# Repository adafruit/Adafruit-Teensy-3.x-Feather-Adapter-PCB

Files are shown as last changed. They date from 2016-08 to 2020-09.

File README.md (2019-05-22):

## Adafruit Teensy 3.x Feather Adapter PCB
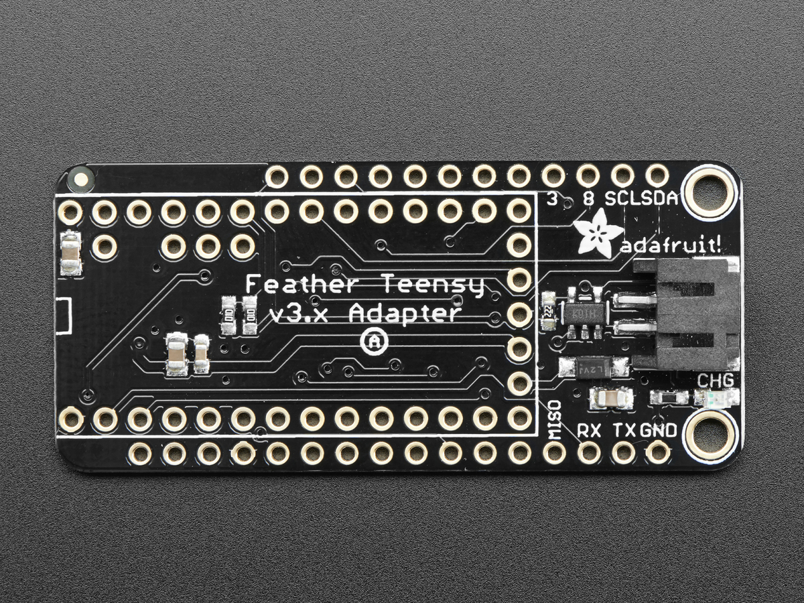
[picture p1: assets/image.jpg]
<a href="http://www.adafruit.com/products/3200"><br/>
Click here to purchase one from the Adafruit shop</a>

This Feather adapter rearranges the pins of a Teensy 3.x to give you the same shape and pinout for our Feathers. We've tested our FeatherWings so far and all are drop-in compatible. It's a great way to take advantage of the Feather ecosystem. Give your Teensy a stepper/DC motor driver, GPS, LED matrix or OLED add-on with ease. With the space left over, we even added in a 500mA LiPoly charger that automatically charges over USB and will switch over to the LiPo when USB is unplugged. There's also a 100K resistor divider for monitoring the battery voltage connected to A7

PCB files for the Adafruit Teensy 3.x Feather Adapter. The format is EagleCAD schematic and board layout
- https://www.adafruit.com/product/3200

### License

Adafruit invests time and resources providing this open source design, please support Adafruit and open-source hardware by purchasing products from [Adafruit](https://www.adafruit.com)!

All text above must be included in any redistribution

Designed by Limor Fried/Ladyada for Adafruit Industries.
Creative Commons Attribution/Share-Alike, all text above must be included in any redistribution. 
See license.txt for additional information.

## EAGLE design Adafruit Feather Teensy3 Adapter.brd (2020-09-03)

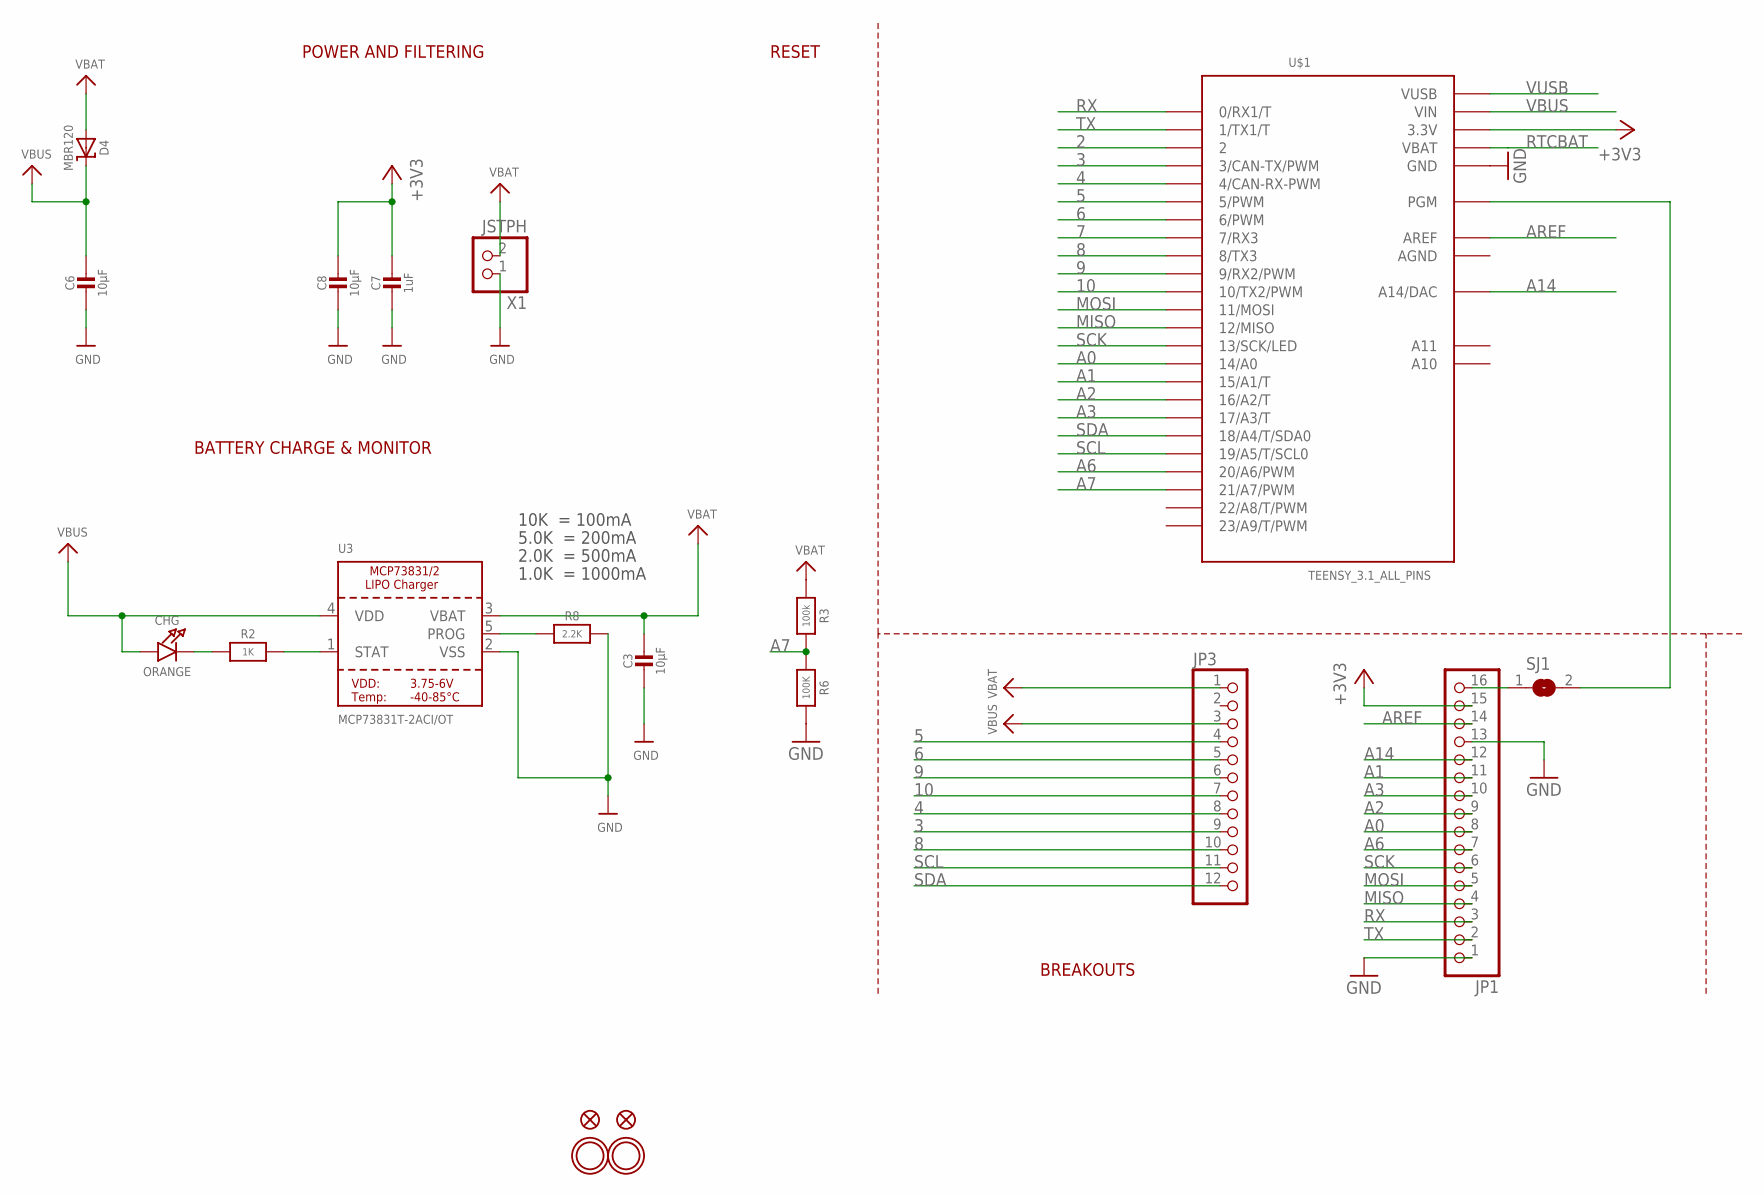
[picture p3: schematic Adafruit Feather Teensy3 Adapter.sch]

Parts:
C3, C6, C8: 10µF; 0805-NO
C7: 1uF; 0603-NO
CHG: ORANGE; CHIPLED_0805_NOOUTLINE
D4: MBR120; SOD-123
JP1: HEADER-1X16ROUND; 1X16_ROUND
JP3: HEADER-1X12; 1X12_ROUND
R2: 1K; 0603-NO
R3: 100k; 0603-NO
R6: 100K; 0603-NO
R8: 2.2K; 0603-NO
SJ1: SOLDERJUMPERCLOSED; SOLDERJUMPER_CLOSEDWIRE
U3: MCP73831T-2ACI/OT; SOT23-5
U$1: TEENSY_3.1_ALL_PINS; TEENSY3-ALL_PINS
U$31, U$32: MOUNTINGHOLE2.5; MOUNTINGHOLE_2.5_PLATED
U$34, U$35: FIDUCIAL""; FIDUCIAL_1MM
X1: JSTPH; JSTPH2

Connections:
2: U$1.2
3: JP3.9, U$1.3 (3/CAN-TX/PWM)
4: JP3.8, U$1.4 (4/CAN-RX-PWM)
5: JP3.4, U$1.5 (5/PWM)
6: JP3.5, U$1.6 (6/PWM)
7: U$1.7 (7/RX3)
8: JP3.10, U$1.8 (8/TX3)
9: JP3.6, U$1.9 (9/RX2/PWM)
10: JP3.7, U$1.10 (10/TX2/PWM)
+3V3: C7.1, C8.1, JP1.15, U$1.3.3V, U$1.3.3V1 (3.3V)
A0: JP1.8, U$1.14/A0
A1: JP1.11, U$1.15/A1 (15/A1/T)
A2: JP1.9, U$1.16/A2 (16/A2/T)
A3: JP1.10, U$1.17/A3 (17/A3/T)
A6: JP1.7, U$1.20/A6 (20/A6/PWM)
A7: R3.2, R6.1, U$1.21/A7 (21/A7/PWM)
A14: JP1.12, U$1.RESET/DAC (A14/DAC)
AGND: U$1.AGND
AREF: JP1.14, U$1.AREF
BOOT: SJ1.2, U$1.PGM
GND: C3.2, C6.2, C7.2, C8.2, JP1.1, JP1.13, R6.2, R8.2, U3.2 (VSS), U$1.GND, U$1.GND1 (GND), X1.1
MISO: JP1.4, U$1.12 (12/MISO)
MOSI: JP1.5, U$1.11 (11/MOSI)
unnamed: CHG.C, R2.1
unnamed: R2.2, U3.1 (STAT)
unnamed: R8.1, U3.5 (PROG)
RST/BOOT: JP1.16, SJ1.1
RTCBAT: U$1.VBAT
RX: JP1.3, U$1.0 (0/RX1/T)
SCK: JP1.6, U$1.13 (13/SCK/LED)
SCL: JP3.11, U$1.19/A5 (19/A5/T/SCL0)
SDA: JP3.12, U$1.18/A4 (18/A4/T/SDA0)
TX: JP1.2, U$1.1 (1/TX1/T)
VBAT: C3.1, D4.A, JP3.1, R3.1, U3.3 (VBAT), X1.2
VBUS: C6.1, CHG.A, D4.C, JP3.3, U3.4 (VDD), U$1.VIN
VUSB: U$1.VUSB

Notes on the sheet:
POWER AND FILTERING
RESET
10K = 100mA
5.0K = 200mA
2.0K = 500mA
1.0K = 1000mA
BATTERY CHARGE & MONITOR
BREAKOUTS

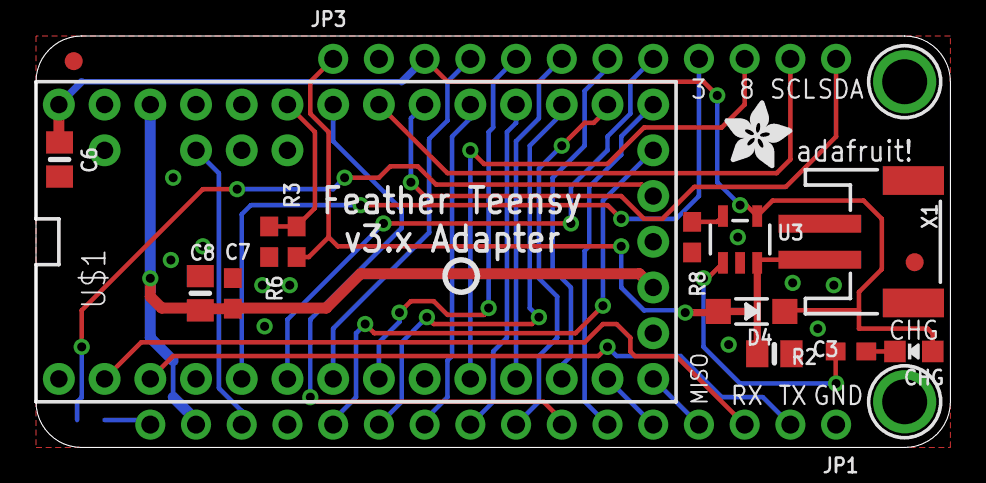
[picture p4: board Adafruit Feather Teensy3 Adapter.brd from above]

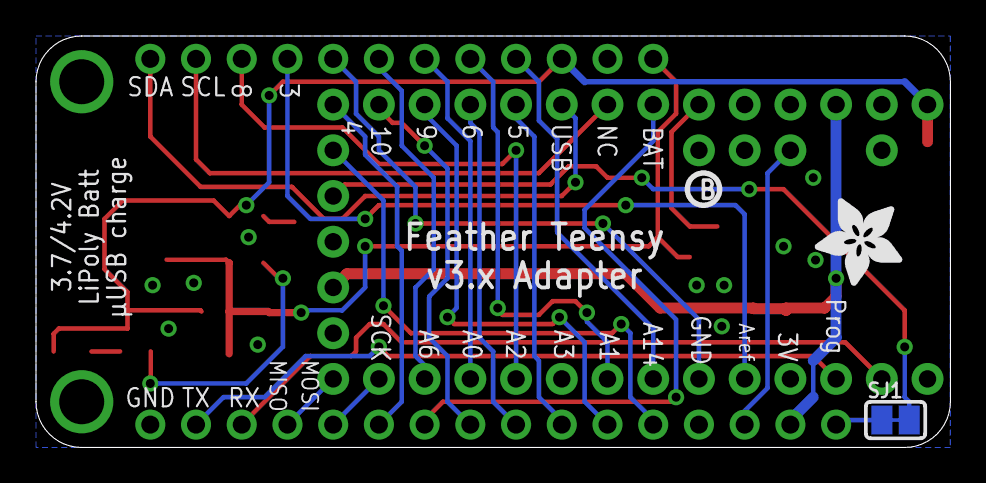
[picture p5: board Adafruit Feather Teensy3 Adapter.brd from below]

Board: 2 copper layers, 50.8 x 22.9 mm, 24 parts (3 on the bottom side), 31 nets.

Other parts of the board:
U$4: ADAFRUIT_5MM
U$5, U$6: PCBFEAT-REV-040
U$7: ADAFRUIT_3.5MM

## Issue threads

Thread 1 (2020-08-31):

Should this show Rev B PCB Layout?

crnorris, 2020-08-31:
PCB Layout appears to show revision A, with VBAT on the Teensy board incorrectly connected to VBAT on the Feather board. Recommend also clarifying whether the VIN - VUSB link should be cut (presumably not).

ladyada, 2020-08-31:
@kattni please add `Development\Dev Boards\Feather Teensy3\Rev B`

kattni, 2020-09-03:
Added!

Closed 2020-09-03.

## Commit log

2020-09-03 Rename file.
    [Adafruit Feather Teensy3 Adapter Original.brd]
2020-09-03 Adding latest board files.
    [Adafruit Feather Teensy3 Adapter.brd, Adafruit Feather Teensy3 Adapter.sch]

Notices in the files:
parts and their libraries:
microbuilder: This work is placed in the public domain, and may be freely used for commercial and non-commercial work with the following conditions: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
